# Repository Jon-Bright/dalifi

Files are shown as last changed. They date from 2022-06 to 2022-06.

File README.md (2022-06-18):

# DaliFi
ESP8266-based PCB and code for WiFi communication with DALI-based devices. DALI is standardized as IEC 62386-102.

This project consists of three parts:

* hardware: Design for a fairly simple through-hole PCB capable of powering a bus, sending and receiving messages to/from DALI-compliant lamps. Design done using EAGLE, Gerber files included.
* library: An Arduino library for communicating with DALI-compliant lamps.
* example: An example Arduino application using the library and providing a WiFi-based interface to control attached lamps.

Each of these is covered in more detail below.

## Hardware

KNOWN BUG: the silkscreen for T2 is incorrect, at least for the 2N2222s I have.

The hardware can be broadly separated into seven parts:

* Mains voltage to 12v conversion.
  * This is done by a self-contained RAC05-12SK unit.
  * The resulting 12v is used to (optionally, see below) power the bus to the lamps, as well as the board itself.
* 12v to 3.3v conversion.
  * Another self-contained unit, RNM-123.3S.
  * The 3.3v is used to power the ESP8266.
* Bus power: this takes the 12v from above and limits its current as well as making it short-tolerant.
  * DALI communication involves frequent shorts of the bus (it's how "low" is communicated).
  * As more power is drawn on the bus (including when it's shorted), the voltage across R2 increases.
  * When the power drawn reaches 144mA, that's a voltage across R2 of 1.44V - and that's equivalent to the forward voltage of the two diodes. Current begins to flow through them.
  * The current flow across the two diodes means the transistor gradually turns off.
  * The current through the diodes is limited by R1, to about 12mA.
  * There are two jumpers after all of this. If something else is powering the bus, disconnect the jumpers and this circuit won't.
* DALI polarity protection.
  * If we're powering the bus, this isn't needed - we know which polarity is in use. But if we're not, then the bus can be either polarity. This rectifier deals with this and gives us plus and minus.
* DALI input.
  * When the DALI+ voltage is high enough (~5.6V) above DALI-, the Zener diode (D3) starts conducting.
  * This causes the LED in optoisolator OK1 to light.
  * R3 limits current across D3 (and through OK1).
  * When the LED in OK1 is active, DALI_I (which is otherwise pulled high by R5) is pulled low by OK1.
* DALI output.
  * When DALI_O is high, the LED in OK2 is active.  (R7 limits current through OK2 and current sourced from the ESP8266.)
  * This in turn causes current to flow to the base of T2 (via current-limiter R4). T2's base is otherwise pulled low by R6.
  * This causes T2 to short DALI+ and DALI-.  (A 2N2222 is good for 600mA continuous current and the DALI bus should be at most 250mA.)
* The ESP8266.
  * We're expecting a board with USB connector and so forth, as opposed to a blank ESP8266.

I am _not_ a hardware engineer. People who are will probably take one look at the design and go cry into pillows. Improvements are very welcome.

## Library

The library:

* Includes metadata for all opcodes (and "opcode addresses" like DAPC, DTR0) in the standard.
* Only implements functions to send a limited subset of those opcodes.
* Implementation of additional opcodes should be trivial.
* Includes functions for assigning short addresses to lamps.
* Handles all aspects of encoding and decoding the Manchester encoding used by devices.
* Is designed to work with the PCB above
  * Any PCB featuring an ESP8266 with two pins assigned to input from and output to DALI-compliant lamps should work, though.
  * If using a different PCB with differently-performing hardware, the timing definitions for half-bits at the top of dali.cpp might need tweaking.

## Example

The example Arduino application uses the library.  It features:

* Saving of WiFi connection using the ESP8266's (fake) EEPROM functionality.
* An Access Point function when no WiFi connection info is saved, to collect and save the information.
* A simple text-based interface for controlling the lamps.
* Commands for controlling lamps and querying their status.

My intention is to add MQTT support in addition to (or in place of) the simple text-based interface.

## Testing

I've tested this with three DALI-compliant lamps in my possession (two from the same manufacturer). It works fine with all of them. I've had it in operation with two of those lamps for a total of ~5 years of runtime without problems. Nevertheless, see the disclaimer of all warranty below.

## Legal

DALI, the DALI Logo, DALI-2, the DALI-2 Logo, DiiA, the DiiA Logo, D4i, the D4i Logo, DALI+ and the DALI+ Logo are trademarks in various countries in the exclusive use of the Digital Illumination Interface Alliance. No claim is made to any of these marks, nor is it claimed that this work is compliant with standards issued by the Alliance.

Absolutely no warranty is given for any element of this work. If it breaks, you get to keep both pieces. If it breaks your lamp(s), same. See the warranty exclusion in LICENSE.

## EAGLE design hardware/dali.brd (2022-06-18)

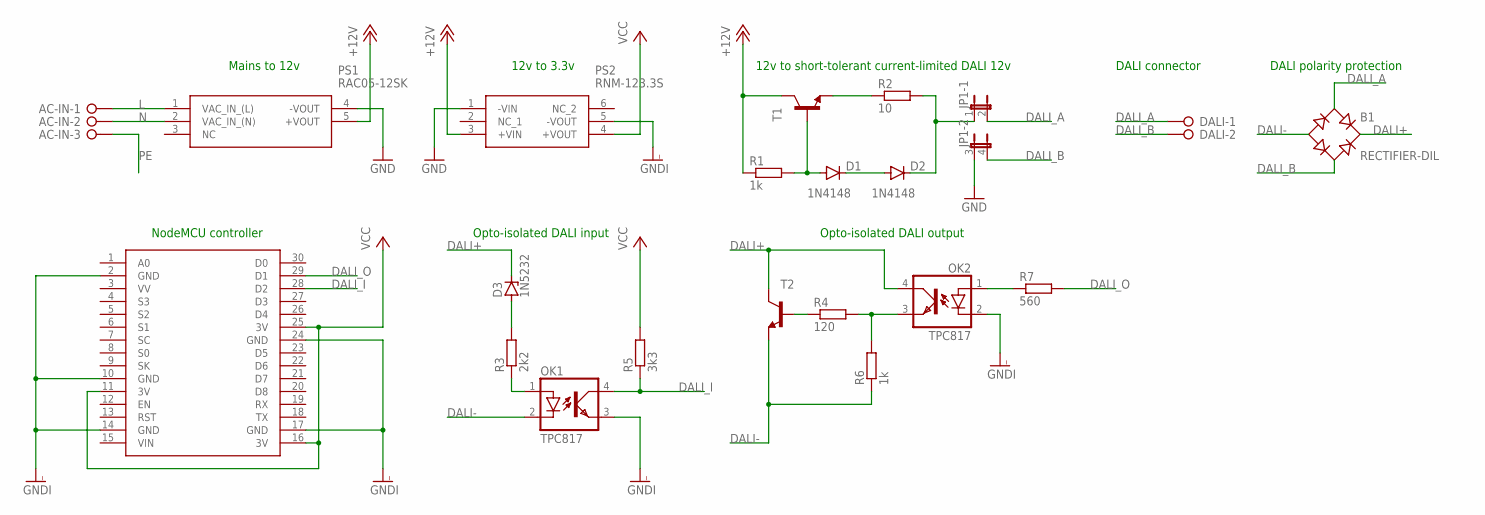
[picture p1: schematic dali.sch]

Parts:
AC-IN: 39544-3003
B1: RECTIFIER-DIL; B-DIL
D1, D2: 1N4148; DO35-10
D3: 1N5232; DO35Z10
DALI: 39544-3002
JP1: JP2QE; JP2Q
OK1, OK2: TPC817; DIL04
PS1: RAC05-12SK
PS2: RNM-123.3S; DIP508W115P254L830H705Q6N
R1, R6: 1k; 0207/7
R2: 10; 0207/7
R3: 2k2; 0207/7
R4: 120; 0207/7
R5: 3k3; 0207/7
R7: 560; 0207/7
T1, T2: MPS2222A-NPN-TO92-CBE; TO92-CBE
U$1: NODEMCU

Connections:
+12V: PS1.5 (+VOUT), PS2.3 (+VIN), R1.1, T1.C
DALI+: B1.+, D3.C, OK2.4 (COL), T2.C
DALI-: B1.-, OK1.2 (C), R6.1, T2.E
DALI_A: B1.AC1, DALI.1, JP1.2
DALI_B: B1.AC2, DALI.2, JP1.4 (2)
DALI_I: OK1.4 (COL), R5.1, U$1.28 (D2)
DALI_O: R7.2, U$1.29 (D1)
GND: JP1.3 (1), PS1.4 (-VOUT), PS2.1 (-VIN)
GNDI: OK1.3 (EMIT), OK2.2 (C), PS2.5 (-VOUT), U$1.2 (GND), U$1.10 (GND), U$1.14 (GND), U$1.17 (GND), U$1.24 (GND)
L: AC-IN.1, PS1.1 (VAC_IN_(L))
N: AC-IN.2, PS1.2 (VAC_IN_(N))
unnamed: D1.A, R1.2, T1.B
unnamed: D1.C, D2.A
unnamed: R2.1, T1.E
unnamed: D3.A, R3.2
unnamed: OK1.1 (A), R3.1
unnamed: R4.1, T2.B
unnamed: OK2.3 (EMIT), R4.2, R6.2
unnamed: OK2.1 (A), R7.1
unnamed: D2.C, JP1.1, R2.2
PE: AC-IN.3
VCC: PS2.4 (+VOUT), R5.2, U$1.11 (3V), U$1.16 (3V), U$1.25 (3V)

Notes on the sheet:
Mains to 12v
12v to 3.3v
12v to short-tolerant current-limited DALI 12v
NodeMCU controller
DALI connector
DALI polarity protection
Opto-isolated DALI input
Opto-isolated DALI output

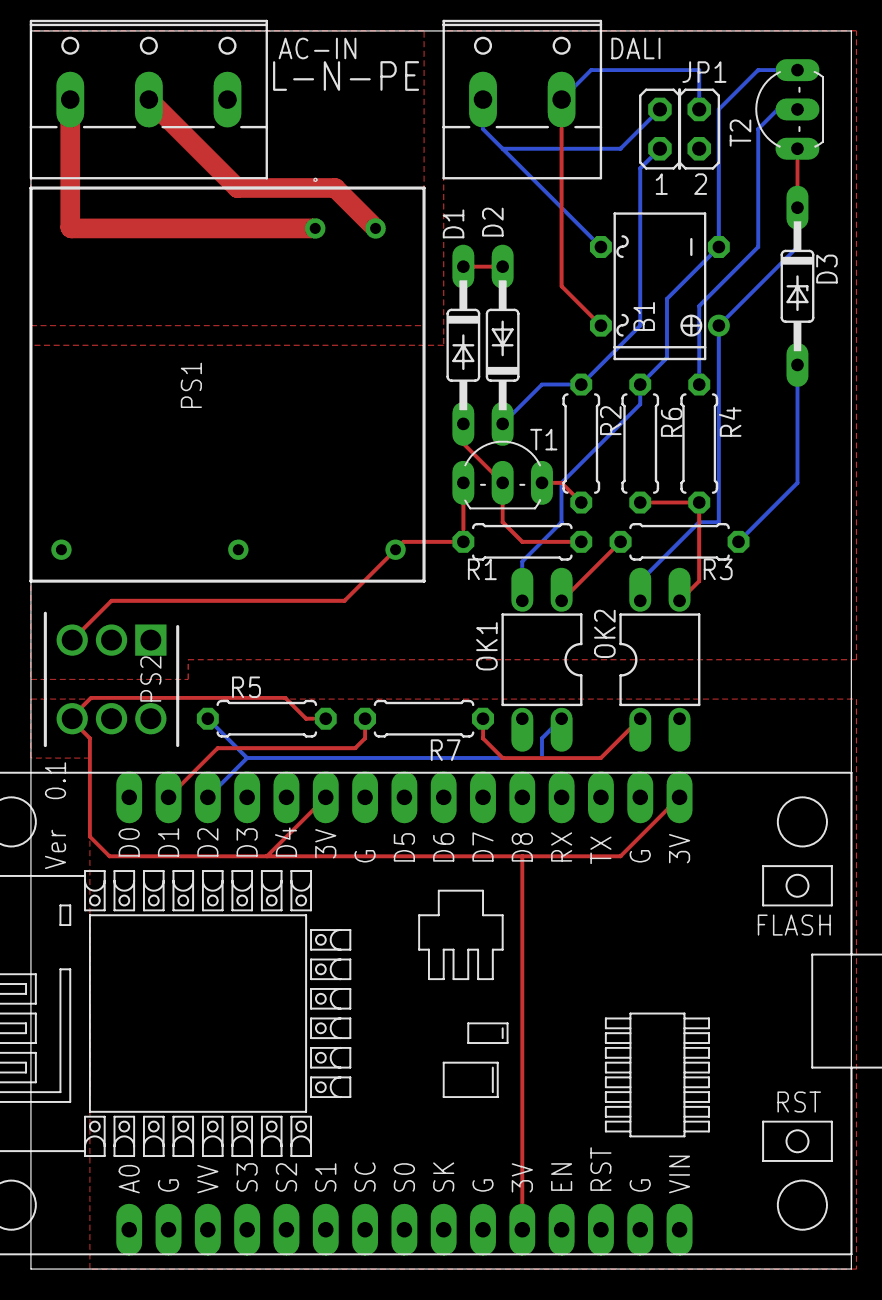
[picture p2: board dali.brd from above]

Board: 2 copper layers, 53.0 x 80.0 mm, 21 parts (0 on the bottom side), 21 nets.

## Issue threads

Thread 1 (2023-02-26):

Self-addressed lamps should be better-supported

marcobrianza, 2023-02-26:
hello, I'm trying to use the lib with a simplified sketch

the broadcast message works
dali->sendDapc(Dali::broadcast, true, 254)

what is the address format for shot address and groups?

https://github.com/Jon-Bright/dalifi/blob/0af19229c89edc85188e68d75797056a1594c5d3/library/dali.cpp#L435
realy confuses me

If I comment it, I can use the method sendDapc with the address as a byte in the DALI standard format.

thank you
Marco

marcobrianza, 2023-03-03:
I have the feeling that  addr ^= 1 inverts the last bit (so it could turn it to 1) when we should have it fixed to 0

Jon-Bright, 2023-03-03:
Ah, I see what you're saying.  This is in fact correct, if you've previously used `reAddressLamps`.  At https://github.com/Jon-Bright/dalifi/blob/0af19229c89edc85188e68d75797056a1594c5d3/library/dali.cpp#L517 you can see that the addresses are returned with the 1 bit already sent, so only sendDapc inverts the bit to zero.  I hadn't considered the case of people doing their own address assignment.  Is that what you're doing?  If so, I'll reopen the issue.

marcobrianza, 2023-03-03:
Yes, I address lamps with a dedicated DALI tool, otherwise I may connect to a DALI bus with already addressed lamps.

Jon-Bright, 2023-03-03:
OK, understood.  I should be able to do a fix for that this weekend.

Jon-Bright, 2023-03-04:
https://github.com/Jon-Bright/dalifi/commit/30ad1835ea71426921f120f218fd47839ef958a7 should resolve this. I've tested it locally, although since I don't have a device to separately address the lamps, I can't check your case (but the change is simple, so I'm pretty sure it'll work). Please let me know!

marcobrianza, 2023-03-04:
hi, thank you, I can test it on monday

marcobrianza, 2023-03-11:
Hi, with the latest code I can send the light level to all kind of addresses.
I created a wrapper function to make it more friendly to use as addr as the number we call it

typedef enum {
  addrBroadcast = 0,
  addrSingle,
  addrGroup
} addrMode_t;

bool sendLevel(addrMode_t addrMode, byte addr, byte level ) {

  if (addrMode == addrBroadcast) {
    if (addr==0) addr= B11111100; //broadcast unadressed
    else addr = B11111110;
  } else if (addrMode == addrSingle) {
    addr = addr << 1;
  } else if (addrMode == addrGroup) {
    addr = addr << 1;
    addr = addr | B10000000;
  }
  return(dali->sendDapc(addr, true, level));
}

Closed 2023-03-11.

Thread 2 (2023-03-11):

sendSetPowerOnLevel does not produce any output

marcobrianza, 2023-03-11:
Hi, going on testing other features I have tried sendSetPowerOnLevel
using the following command
dali->sendSetPowerOnLevel(B00000011, true, 42);

I expect this to set power on level to 42 for address 1
There is no effect and I see no output on the DALI bus using a DALI sniffer, am I using it wrong?

Jon-Bright, 2023-08-04:
Apologies for the delayed reply. That should work. Does it return `false`, indicating an error? If it does, what does `getError()` give you? Given that there's nothing on the bus, my vague suspicion is that it's going to give you `eWaitPri` (=1), indicating that it waited for the bus to become idle but that didn't happen.

marcobrianza, 2023-08-04:
Hi, thank you for following up. I'm currently on vacation, I can bring things up again to test in September

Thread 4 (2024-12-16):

Short Address assign

rofacz, 2024-12-16:
Hello,
is there any reason why the devices are not assigned by consecutive short addresses?
First device gets address 0, next 2,....
This is caused in  daliAddr* Dali::reAddressLamps(byte *num)
by:
 *num = shortAddr;
  for (byte b = 0; b < shortAddr; b++) {
    ret[b] = b << 1;
  }
DALI accepts 64 devices on the bus (0..63), but there is the out of range formula.
If I am correct, the ret[b] = b; shoud be used.

Jon-Bright, 2025-01-01:
Hi,

tl;dr: all 64 addresses are usable, the short addresses getting assigned are correct, just the byte being returned is shifted up by one bit, for reasons.

The address byte for DALI commands with short addresses is:

* Bit 7 (top bit): 0
* Bits 6-1: the short address (6 bits, 64 addresses)
* Bit 0 (low bit): 1 for standard commands, 0 for DAPC (direct arc power control) commands

Sending of the address to the lamp is happening in `findDevice`: https://github.com/Jon-Bright/dalifi/blob/30ad1835ea71426921f120f218fd47839ef958a7/library/dali.cpp#L572

The DALI "set short address" command also takes the address shifted up by one bit.

By storing the address pre-shifted, we avoid having to shift it everywhere else, when sending commands.

In `sendLampOff`, for example, you can see that we're setting bit 0 to 1, because this is a standard command: https://github.com/Jon-Bright/dalifi/blob/30ad1835ea71426921f120f218fd47839ef958a7/library/dali.cpp#L424
By contrast in `sendDapc`, nothing is getting set in the bottom bit, meaning it stays as 0 and this is a DAPC command: https://github.com/Jon-Bright/dalifi/blob/30ad1835ea71426921f120f218fd47839ef958a7/library/dali.cpp#L438

The reason DAPC commands are different: they're sent to a specific lamp (or group of lamps, etc.), but they need to send a level. Thus, the command itself is encoded in the bottom bit of the address byte, while the level is encoded in the opcode byte.

Hope this helps!

Thanks

Jon

rofacz, 2025-01-02:
Thans for detailed description!
Meanwhile I changed little bit the addressing in library to get better compatibility with my app.

Closed 2025-01-01.

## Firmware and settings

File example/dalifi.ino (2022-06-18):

#include <ESP8266WiFi.h>
#include <Client.h>
#include <dali.h>

#define PIN_LED_BUILTIN 2 // D4
#define PIN_DALI_O 5 // D1
#define PIN_DALI_I 4 // D2

#define LED_ACTIVE LOW
#define LED_INACTIVE HIGH

typedef enum {
  blinkResetFailed = 1,
  blinkLampOffFailed,
  blinkNotAllLampsFound,
  blinkQueryPowerOnLevelFailed,
  blinkPowerOnLevelSetFailed,
  blinkOTAFailed,
} blinkLongCode;

Dali *dali;
daliAddr *addrs;
byte nLamps;

// RTC memory gives us 512 bytes, so these 33+1+1+1+64+4=104 will fit fine
struct __attribute__((packed, aligned(4))) DaliFiConfig {
  char ssid[33];      // SSIDs are allowed to be at most 32 chars, plus terminator
  byte nLamps;        // The number of lamps we expect to find
  byte powerOnLvl;    // The level at which the lamps should be when powered on, 0-254 (will be restricted by min/max)
  byte pad;           // Padding to make config struct a multiple of 4 bytes
  char password[64];  // Passwords can be 63 chars, plus terminator
  uint32_t crc;       // CRC to ensure the data we read is valid
} daliFiConfig;

void blinkCode(blinkLongCode longFlash, byte shortFlash, const char* logBuf) {
  for (byte x=0; x != 4; x++) {
    for (byte i = 0; i != (byte)longFlash; i++) {
      digitalWrite(PIN_LED_BUILTIN, LED_ACTIVE);
      delay(600);
      serveWiFi(logBuf);
      digitalWrite(PIN_LED_BUILTIN, LED_INACTIVE);
      delay(600);
      serveWiFi(logBuf);
    }
    delay(1000);
    for (byte i = 0; i != shortFlash; i++) {
      digitalWrite(PIN_LED_BUILTIN, LED_ACTIVE);
      delay(200);
      serveWiFi(logBuf);
      digitalWrite(PIN_LED_BUILTIN, LED_INACTIVE);
      delay(300);
      serveWiFi(logBuf);
    }
    delay(2000);
    serveWiFi(logBuf);
  }
  ESP.restart();
}

void setup() {
  Serial.begin(115200);
  Serial.println("setup");
  Serial.flush();
  pinMode(PIN_LED_BUILTIN, OUTPUT);
  digitalWrite(PIN_LED_BUILTIN, LED_INACTIVE);
  setupWiFi();

  dali = new Dali(PIN_DALI_I, PIN_DALI_O);
  dali->init();
  dali->log("init\n");
  delay(2000);
  if (!dali->sendReset(Dali::broadcast)) {
    blinkCode(blinkResetFailed, dali->getError(), dali->getLogBuf());
  }
  dali->log("reset sent\n");
  delay(1000);
  if (!dali->sendLampOff(Dali::broadcast, false)) {
    blinkCode(blinkLampOffFailed, dali->getError(), dali->getLogBuf());
  }
  dali->log("lamp-off sent\n");
  digitalWrite(PIN_LED_BUILTIN, LED_ACTIVE);
  delay(200);
  digitalWrite(PIN_LED_BUILTIN, LED_INACTIVE);
  delay(2000);
  addrs = dali->reAddressLamps(&nLamps);
  dali->log("lamps addressed, nLamps %d\n", nLamps);
  if (addrs == NULL || nLamps != daliFiConfig.nLamps) {
    blinkCode(blinkNotAllLampsFound, dali->getError(), dali->getLogBuf());
  }
  for (int i = 0; i < nLamps; i++) {
    int pol = dali->queryPowerOnLevel(addrs[i], false);
    if (pol < 0) {
      blinkCode(blinkQueryPowerOnLevelFailed, dali->getError(), dali->getLogBuf());
    }
    dali->log("lamp %d, got pol %d, want %d\n", i, pol, daliFiConfig.powerOnLvl);
    if (pol == daliFiConfig.powerOnLvl) {
      // Power-on level already set to what we want, next lamp
      continue;
    }
    if (!dali->sendSetPowerOnLevel(addrs[i], false, daliFiConfig.powerOnLvl)) {
      blinkCode(blinkPowerOnLevelSetFailed, dali->getError(), dali->getLogBuf());
    }
  }
  dali->log("boot complete, %d lamps\n", nLamps);
}

byte getNumLamps(void) {
  return nLamps;
}

const char *stepOnUp(bool fromUser) {
  for (int i = 0; i < nLamps; i++) {
    if (!dali->sendOnStepUp(addrs[i], fromUser)) {
      return "Failed OSU";
    }
  }
  return NULL;
}

const char *stepDownOff(bool fromUser) {
  for (int i = 0; i < nLamps; i++) {
    if (!dali->sendStepDownOff(addrs[i], fromUser)) {
      return "Failed SDO";
    }
  }
  return NULL;
}

const char *setLevel(bool fromUser, byte level) {
  for (int i = 0; i < nLamps; i++) {
    if (!dali->sendDapc(addrs[i], fromUser, level)) {
      return "Failed DAPC";
    }
  }
  return NULL;
}

const char *query(bool fromUser, int *lvl) {
  for (int i = 0; i < nLamps; i++) {
    lvl[i] = dali->queryActualLevel(addrs[i], fromUser);
    if (lvl[i] < 0) {
      return "Failed QAL";
    }
  }
  return NULL;
}

const char *queryMin(bool fromUser, int *lvl) {
  for (int i = 0; i < nLamps; i++) {
    lvl[i] = dali->queryMinLevel(addrs[i], fromUser);
    if (lvl[i] < 0) {
      return "Failed QMinL";
    }
  }
  return NULL;
}

const char *queryMax(bool fromUser, int *lvl) {
  for (int i = 0; i < nLamps; i++) {
    lvl[i] = dali->queryMaxLevel(addrs[i], fromUser);
    if (lvl[i] < 0) {
      return "Failed QMaxL";
    }
  }
  return NULL;
}

void loop() {
  serveWiFi(dali->getLogBuf());
}

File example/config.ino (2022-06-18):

#include <ESP8266WebServer.h>
#include <DNSServer.h> 
#include <EEPROM.h>

#define DNS_PORT 53

const char *apModeSSID = "DaliFi";
const IPAddress apModeIP(192,168,74,66);
const IPAddress apModeGateway(192,168,74,0);
const IPAddress apModeSubnet(255,255,255,0);

DNSServer dnsServer;
ESP8266WebServer configServer(80);
unsigned long reboot;

uint32_t calculateCRC32(const uint8_t *data, size_t length) {
  uint32_t crc = 0xffffffff;
  while (length--) {
    uint8_t c = *data++;
    for (uint32_t i = 0x80; i > 0; i >>= 1) {
      bool bit = crc & 0x80000000;
      if (c & i) { bit = !bit; }
      crc <<= 1;
      if (bit) { crc ^= 0x04c11db7; }
    }
  }
  return crc;
}

bool readAndVerifyConfig() {
  EEPROM.begin(sizeof(daliFiConfig));
  EEPROM.get(0, daliFiConfig);
  if (!EEPROM.end())
    return false;  // Not actually a failure, but we might as well keep it in mind
  uint32_t crc = calculateCRC32((uint8_t*)&daliFiConfig, sizeof(daliFiConfig)-sizeof(uint32_t));
  return crc == daliFiConfig.crc; // If our calculated CRC matches the CRC we read, the saved info is valid
}

void resetConfig() {
  memset(&daliFiConfig, 0, sizeof(daliFiConfig));
  EEPROM.begin(sizeof(daliFiConfig));
  EEPROM.put(0, daliFiConfig);
  EEPROM.end();
}

void handleRoot() {
  configServer.send(200, "text/html", 
    F("<html>"
      " <head>"
      "  <title>DaliFi</title>"
      " </head>"
      " <body>"
      "  <h1>DaliFi</h1>"
      "  <form method='post' action='setconfig'>"
      "   <table>"
      "    <tr>"
      "     <td>SSID"
      "     <td><input name='ssid' length='20'>"
      "    <tr>"
      "     <td>Password"
      "     <td><input name='pass' length='20'>"
      "    <tr>"
      "     <td>Number of lamps"
      "     <td><input name='lamps' length='5'>"
      "    <tr>"
      "     <td>Power-on level"
      "     <td><input name='pol' length='5'>"
      "    <tr>"
      "     <td colspan=2><input type='submit' value='Save and restart'>"
      ));
}

void handleSetConfig() {
  if (!configServer.hasArg("ssid")) {
    configServer.send(500, "text/plain", "Missing ssid");
    return;
  }
  if (!configServer.hasArg("pass")) {
    configServer.send(500, "text/plain", "Missing pass");
    return;
  }
  if (!configServer.hasArg("lamps")) {
    configServer.send(500, "text/plain", "Missing lamps");
    return;
  }
  if (!configServer.hasArg("pol")) {
    configServer.send(500, "text/plain", "Missing pol");
    return;
  }
  configServer.setContentLength(CONTENT_LENGTH_UNKNOWN); // This prevents .send() sending a Content-Length header that stops subsequent messages from getting through.
  configServer.send(200, "text/plain", "Setting config...\n");
  configServer.arg("ssid").toCharArray(daliFiConfig.ssid, sizeof(daliFiConfig.ssid));
  configServer.arg("pass").toCharArray(daliFiConfig.password, sizeof(daliFiConfig.password));
  daliFiConfig.nLamps = configServer.arg("lamps").toInt();
  daliFiConfig.powerOnLvl = configServer.arg("pol").toInt();
  configServer.sendContent(String("ssid: ")+String(daliFiConfig.ssid)+String("\npass: ")+String(daliFiConfig.password)+String("\nlamps: ")+String(daliFiConfig.nLamps)+String("\npower-on level: ")+String(daliFiConfig.powerOnLvl)+String("\n"));
  daliFiConfig.crc = calculateCRC32((uint8_t*)&daliFiConfig, sizeof(daliFiConfig)-sizeof(uint32_t));
  EEPROM.begin(sizeof(daliFiConfig));
  EEPROM.put(0, daliFiConfig);
  EEPROM.end();
  configServer.sendContent("Wrote config\n");
  memset(&daliFiConfig, 0, sizeof(daliFiConfig));
  if (readAndVerifyConfig()) {
    configServer.sendContent("Config verified! Rebooting in 5s...\n");
    reboot = millis()+5000; // This doesn't work if millis is about to wrap around. Don't care.
  } else {
    configServer.sendContent("Config read-back failed!\n");
  }
}

void wiFiAPMode() {
  WiFi.softAPConfig(apModeIP, apModeGateway, apModeSubnet);
  WiFi.softAP(apModeSSID);
  setupArduinoOTA();
  dnsServer.start(DNS_PORT, "*", apModeIP);
  configServer.on("/", handleRoot);
  configServer.on("/setconfig", handleSetConfig);
  configServer.begin();

  while (true) {
    delay(100);
    if (reboot!=0 && millis()>reboot) {
      ESP.restart();
    }
    handleArduinoOTA();
    dnsServer.processNextRequest();
    configServer.handleClient();
  }
}

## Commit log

2022-06-18 First released version of the project. Full details in README.md.
    [dali.brd, dali.sch]
2022-06-18 Actually use the EEPROM functionality rather than RTC memory. I'd understood these to be two APIs to the same place, but that's not the case - and RTC memory may not survive a power cycle.
2023-03-04 Properly support self-addressed lamps.
    In sent commands, the bottom bit of the address byte determines whether this
    is a DAPC (Direct Arc Power Control) command or not. If the bit is zero, it's
    a DAPC command, otherwise it's not.
    We were previously dealing with this by, in reAddressLamps, setting the bottom
    bit and in sendDapc, clearing it. This worked fine if using reAddressLamps, but
    was broken if someone was addressing their own lamps.
    Switch to not setting the bit in reAddressLamps, setting it when sending all
    other commands and not doing anything in sendDapc.
